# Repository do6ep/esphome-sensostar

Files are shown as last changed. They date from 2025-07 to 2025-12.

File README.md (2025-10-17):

# esphome-sensostar

**Custom ESPHome Component for Engelmann SensoStar Heat Meters**

This ESPHome integration enables reading detailed heat consumption data from Engelmann SensoStar U heat meters and makes it available in Home Assistant.

Same as Project from STB3 but this one uses "ESP32-C3 Super Mini" **including PCB-Data** for production.

Boards can currently be ordered from AISLER (https://aisler.net/p/IZCPMTQC).

** Now testing with "Xaio ESP32S3" this Module is more powerfull.
** Rev. 2 with "Xaio ESP32S3" is in work.

---

## 🔧 Features

- 📊 **Sensor Readings**
  - Energy consumption (kWh)
  - Flow rate (m³/h)
  - Volume (m³)
  - Power (W)
  - Flow temperature (°C)
  - Return temperature (°C)
  - Temperature difference (ΔT)
  - Meter status (text)
  - Battery voltage (via ADC)
  - Battery Status

- 🧠 **Home Assistant Integration**
  - Native API support
  - OTA updates
  - Web dashboard (optional)

- 🔗 **MQTT Integration**
  - Configurable MQTT support via web UI (thanks to the work of STB3)

- 🕹 **Controls**
  - Template button in Home Assistant for instant battery reading
  - Template button in Home Assistant for instant Wi-Fi signal strength reading

- 💡 **LED Indicators**
  - Wi-Fi connection status
  - New data received from the SensoStar meter
  - Heartbeat (device activity, via builtin LED)

---

## 🧪 Requirements

- ESP32-C3 SuperMini (4MB Flash) or Xaio ESP32S3 (4MB Flash) 
- Engelmann SensoStar U or E meter without any optional interfaces
- ESPHome installed on your system
- Home Assistant (optional but recommended)

---

## 🔌 Hardware Wiring

The SensoStar meter uses a 12-pin internal connector for communication and power. Below is the pinout and how to wire it to an ESP32:

| Pin | Function | Connection |
|-----|---|---|
| 1 | NC | — |
| 2 | GND | Connect to ESP32 GND |
| 3 | VCC | Connected to the internal battery of the meter |
| 4 | NC | — |
| 5 | RX | Connect to ESP32 UART TX |
| 6 | TX | Connect to ESP32 UART RX |
| 7 | NC | — |
| 8 | NC | — |
| 9 | NC | — |
|10 | HW Detect (56kΩ to GND) | Connect a 56kΩ resistor to GND |
|11 | NC | — |
|12 | GND | Connect to ESP32 GND |

> **Note:** "NC" means *Not Connected*. Be sure to use level shifting or protective circuitry if needed, depending on your ESP32 model and power requirements.

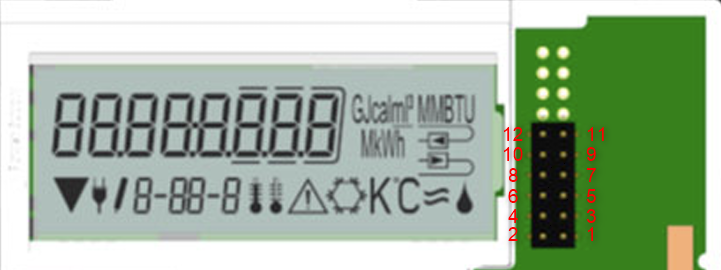
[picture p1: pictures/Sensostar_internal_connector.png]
SensoStar Hardware


---

## 📷 Example Hardware

Below is a visual example of the wired hardware setup.

### Image

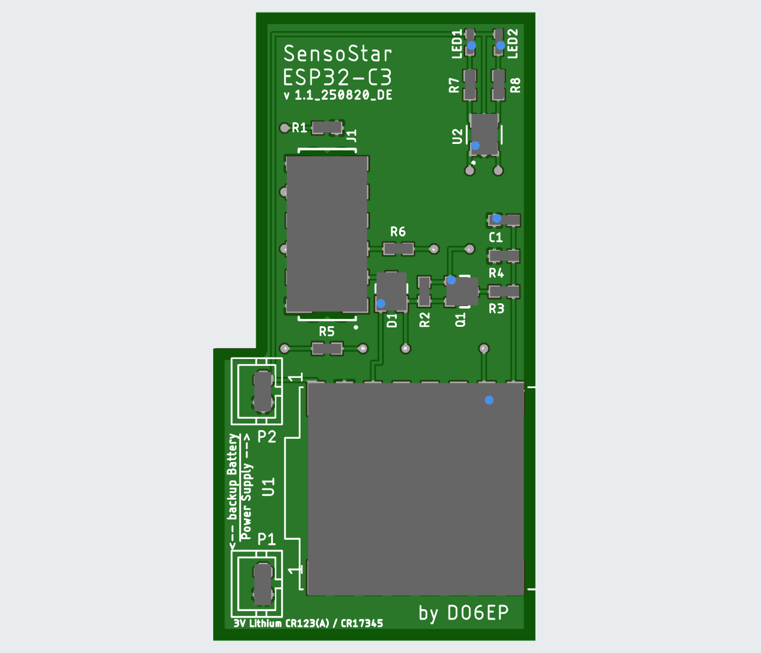
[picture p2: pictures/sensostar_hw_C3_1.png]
SensoStar Hardware Example


### Web-Interface

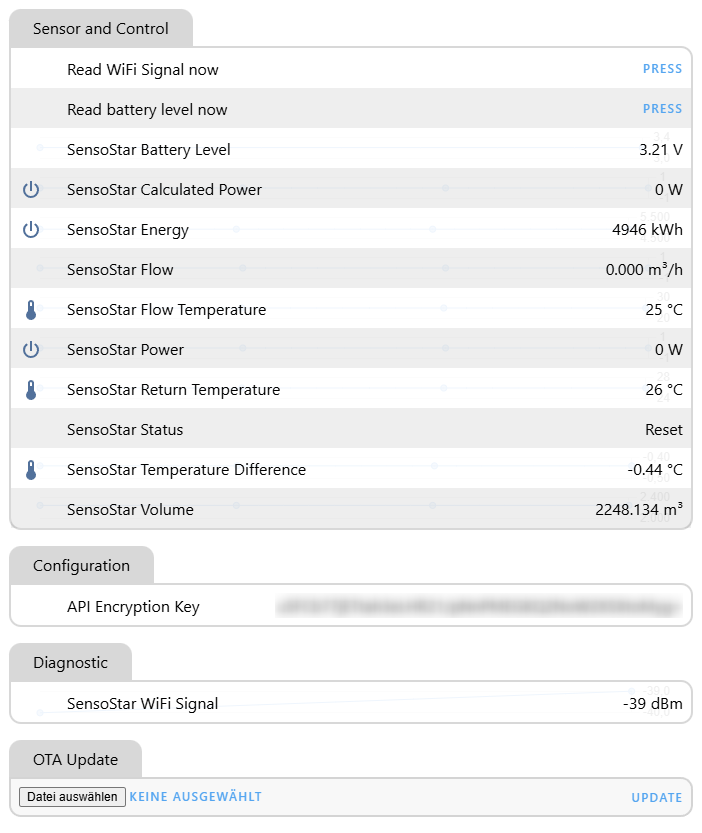
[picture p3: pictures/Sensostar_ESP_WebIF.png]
SensoStar Hardware Example


### Schematics

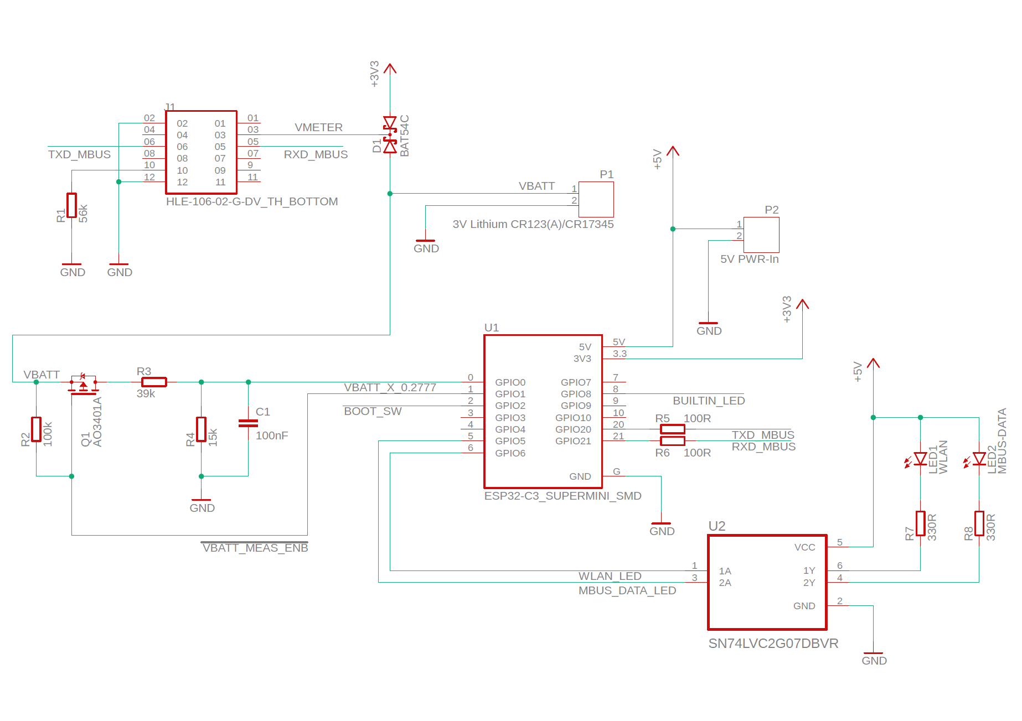
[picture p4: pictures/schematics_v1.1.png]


---

## 🚀 Setup Instructions

1. **Install ESPHome**  
   [ESPHome installation guide](https://esphome.io/guides/installing_esphome.html)

2. **Clone or reference this repository** in your ESPHome config:
   ```yaml
   external_components:
     - source:
         type: git
         url: https://github.com/do6ep/esphome-sensostar
       components: [ SensoStar_MBus ]
   ```

3. **Create a `secrets.yaml` file** in the same folder as your ESPHome config file (`sensostar.yaml`):

   ```yaml
   # secrets.yaml
   wifi_ssid: "YourSSID"
   wifi_password: "YourPassword"
   api_encryption_key: "YourAPIKey"  # Generate with: openssl rand -base64 32
   ```
   [Generate the key online](https://www.cryptool.org/en/cto/openssl/)
   
4. **Build and upload your firmware:**
   ```bash
   cd path\to\your\config
   esphome run sensostar.yaml
   ```
   
5. **Fallback in case no credential were found**

   You can then access the device's web interface at the default IP address 192.168.4.1
   and enter your SSID and password

---

## 📦 Repository Contents

- `components/SensoStar_MBus/`: Custom ESPHome component for the SensoStar M-Bus meter
- No user-specific configuration files are committed (e.g. `sensostar.yaml` or `secrets.yaml`)

---

## 🔐 Security Note

This repository **does not** contain any private configurations. Be sure to:
- Use `secrets.yaml` to keep credentials out of your main config
- Add `.gitignore` rules to exclude secrets from being committed

```gitignore
# .gitignore
secrets.yaml
*.key
*.pem
```

---

## 📫 Contact

Maintained by **do6ep**  
For issues or feature requests, open an issue in the [GitHub repository](https://github.com/do6ep/esphome-sensostar/issues).

---

## 📝 License

This project is open-source and licensed under the MIT License.

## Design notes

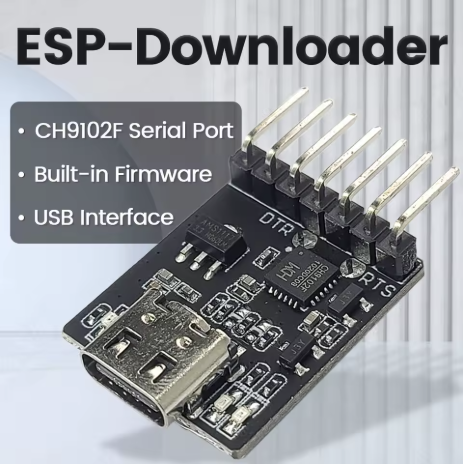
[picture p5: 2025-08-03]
pictures/programming_adapter.png

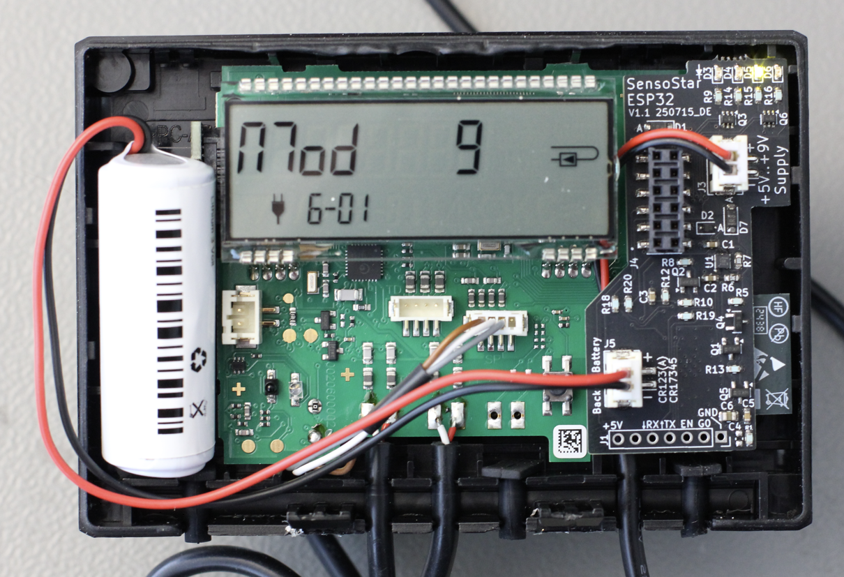
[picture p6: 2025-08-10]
pictures/Sensostar_w_ESP32_Sensostar.png

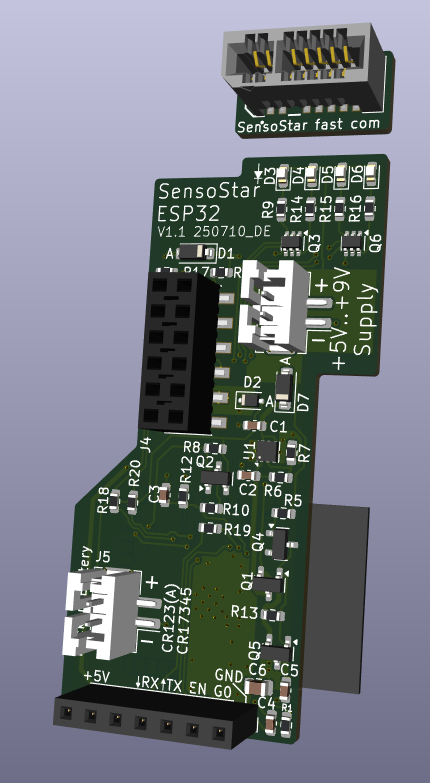
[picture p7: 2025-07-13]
pictures/sensostar_hw_2.png

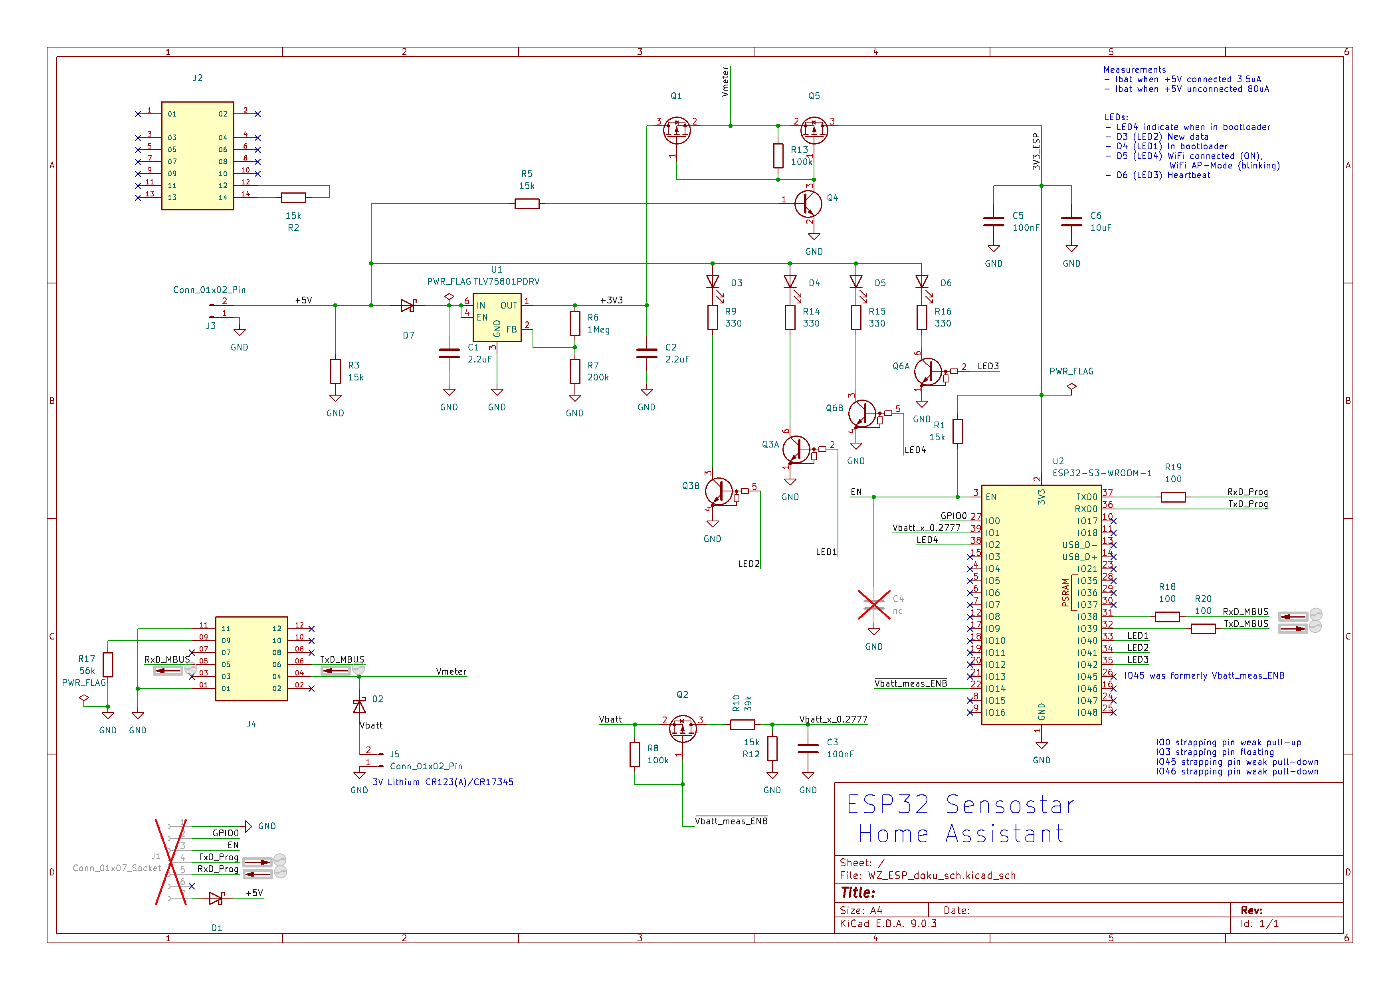
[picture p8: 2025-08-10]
pictures/ESP32_Sensostar.png

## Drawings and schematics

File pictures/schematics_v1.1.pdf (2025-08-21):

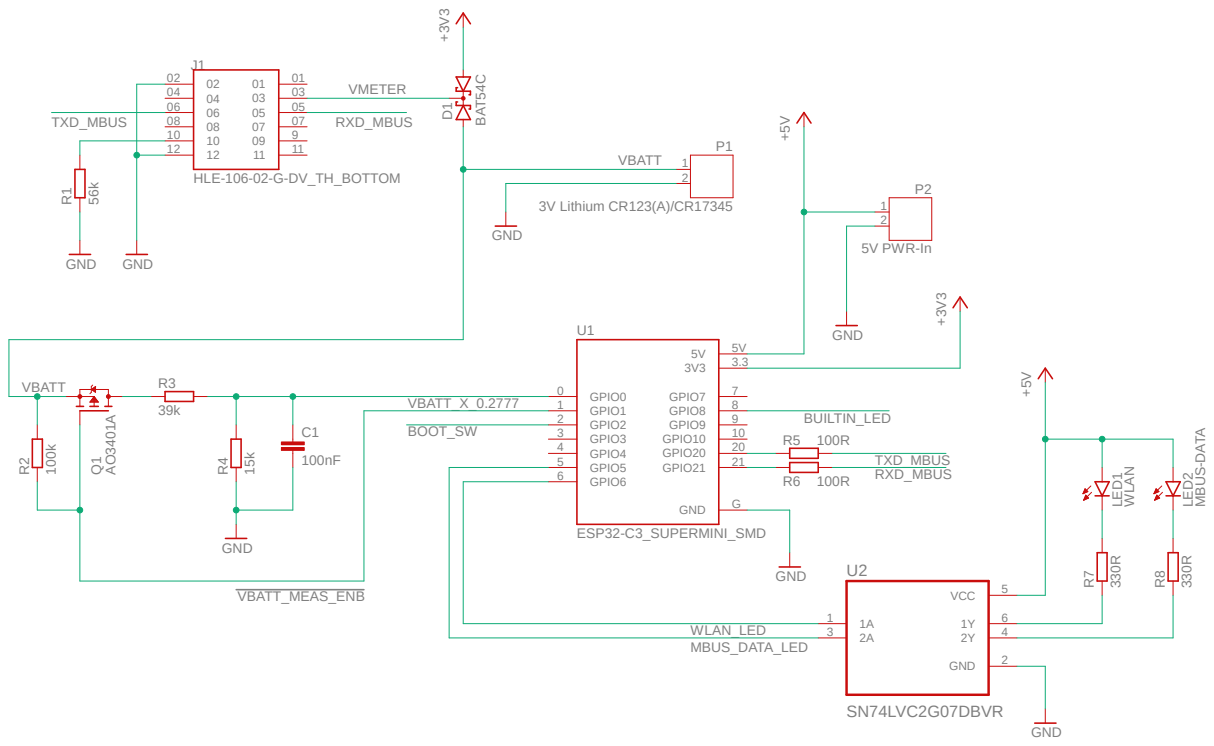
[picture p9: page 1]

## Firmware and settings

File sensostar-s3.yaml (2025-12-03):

esphome:
  # Name of the ESP32-S3 device
  name: sensostar
  friendly_name: SensoStar
  comment: SensoStar Energy Meter
  name_add_mac_suffix: true
  project:
    name: "do6ep.SensoStar_Energy_Meter"
    version: 1.0.2

  # PlatformIO build options
  platformio_options:
    build_flags: -DBOARD_HAS_PSRAM
    board_build.arduino.memory_type: qio_opi
    board_build.f_flash: 80000000L
    board_build.flash_mode: qio

  on_boot:
    then:
      - output.turn_on: adc_control  # IO8 HIGH at boot
      - script.execute: read_adc_script  # Immediately read ADC once at boot
      - delay: 2000ms  # Kurze Wartezeit, damit WLAN-Status gesetzt wird
      - lambda: |-
          if (!id(wifi_connected)) {
            id(ap_mode_blink).execute();
          }      
      - if:
          condition:
            switch.is_on: mqtt_client_switch
          then:
            - wait_until:
                condition:
                  wifi.connected: {}
                timeout: 60s   # Warte bis 60 Sekunden, bis WLAN verbunden ist
            - mqtt.enable
            - logger.log: "MQTT beim Start aktiviert"
          else:
            - mqtt.disable
            - logger.log: "MQTT beim Start deaktiviert"
    
# Configuration for Xaio ESP32S3
esp32:
  board: esp32-s3-devkitc-1
  cpu_frequency: 80MHZ  # keep the CPU cool
  framework:
    type: esp-idf

# activate PSRAM for ESPHome
psram:
  mode: octal
  speed: 80MHz

# Enable logging
logger:
  level: debug

#  level: info
  logs:
    light: info
#  hardware_uart: USB_CDC

api:
  encryption:
    key: !secret api_encryption_key # create use openssl rand -base64 32

ota:
  platform: esphome

# Disable onboard bluetooth (powersave / because its not used)
esp32_ble:
  enable_on_boot: False

wifi:
# Uncomment this if you have ented your credentials in the secrets.yaml
# anyway at least the api_encryption_key: section must be present in the secrets.yaml
#  ssid: !secret wifi_ssid
#  password: !secret wifi_password
  reboot_timeout: 0s 
  output_power: 16.5dB  # reduce WLAN Power to keep the CPU cool or increment to 20.5dB if needed
  enable_btm: true
  enable_rrm: true
  power_save_mode: none
  fast_connect: false

  on_connect:
    - script.stop: ap_mode_blink
    - output.turn_on: wifi_led
  on_disconnect:
    - script.execute: ap_mode_blink

  # Optional manual IP
  #manual_ip:
  #  static_ip: 192.168.230.114
  #  gateway: 192.168.230.1
  #  subnet: 255.255.255.0
  #  dns1: 192.168.230.1

  # Enable fallback hotspot (captive portal) in case wifi connection fails
  ap:
    ssid: "SensoStar Fallback Hotspot"
    password: "01234567"  # please change pasword for fallback hotspot

# Captive portal configuration
captive_portal:

web_server:
  version: 3
  port: 80

mqtt:
  id: mqtt_client
  broker: ""      # IP of your MQTT-Host, will be set trough GUI
  username: ""    # MQTT User Name, will be set trough GUI
  password: ""    # MQTT Password, will be set trough GUI
  enable_on_boot: false
  keepalive: 15s

external_components:
  - source:
      #type: local
      #path: !secret local_path
      type: git                                         # Be careful ESPhome is caching the repository. Do the following to update the cache
      url: https://github.com/do6ep/esphome-sensostar    # Deleting the .esphome/external_components/ cache, or 
      ref: main  # or a specific commit SHA             # Using a ref: to pin to a specific commit or branch.
    components: [ SensoStar_MBus ]

time:
  - platform: sntp
    id: sntp_time
    timezone: Europe/Amsterdam
    servers: ["0.de.pool.ntp.org", "1.de.pool.ntp.org", "2.de.pool.ntp.org"]

uart:
  - id: uart_mbus
    tx_pin: GPIO43
    rx_pin: GPIO44
    baud_rate: 2400
    parity: EVEN
    
SensoStar_MBus:
  id: sensostar_id
  uart_id: uart_mbus
  update_interval: 10s
  data_led: mbus_data_led # Add this line, linking to the output below
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

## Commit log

2025-01-21 Update sensostar.yaml
    - Add captive_portal
    - Add rx_full_threshold on mbus uart
2025-07-08 Changed README.md Add support for Homeassistant Add support for reading the internal battery level
2025-07-09 Update README.md Add new feature: LED toggling when new data from Sensostar was read
2025-07-13 Add special scaling to ADC. Based on multimeter measurements.
2025-07-13 Changed adc update interval to never. interval: is used to trigger the adc. Update README.md
2025-07-21 Add power calculation
    Add software power calculation
2025-07-30 Improved README.md Add blinking of wifi LED when not connected / in AP mode
2025-08-03 Add new image Update README.md Add switch to disable PSRAM when using ESP-IDF
2025-08-10 Add schematics
2025-10-17 adding Xaio ESP32S3 config
2025-12-03 fix energy calculation
    * fix keeping track of last energy calculation time
    * add kWh instead of Wh to "official" energy value
    * avoid integer division
    [sensostar-s3.yaml]
